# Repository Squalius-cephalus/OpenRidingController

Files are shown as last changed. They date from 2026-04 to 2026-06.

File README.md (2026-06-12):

# OpenRidingController
A horse riding game controller for the PC/Mac. The idea is to emulate basic horse riding behaviors and converts those to work a variety of video games.

The controller mainly uses **RP2040 Zero**, **TCRT5000** IR modules and 3D printed parts. Code uses **[CircuitPython 10](https://circuitpython.org/board/waveshare_rp2040_zero/)** for fast prototyping, later revisions may move to Arduino C or something similar.

Currently the controller can emulate keyboard, mouse and DirectInput controller, however, this wont work on any "keyboard to game console" adapter, because of how the USB composite system works.
## Revision 2
Latest revision uses a PCB, and the goal is to minimize the number of 3D printed parts. Strirrups uses an IMU sensors, so controller can be adapted to different frames easily.

OpenRidingController rev.2

Build guide and BOM in the works.

## Revision 1
Handwired design, frame, sensors etc uses many 3D printed parts. Not in active develoment. 

OpenRidingController rev.1

## Video
Video about the project (http://www.youtube.com/watch?v=zyoOwf0pp80 "OpenRidingController")

## Hardware Required

 - RP2040 Zero
 - 4 pcs TCRT5000 Infrared Reflective Sensor (with analog out)
 - [3D Printed parts, steel pipes and M3 hardware](https://github.com/Squalius-cephalus/OpenRidingController/tree/main/3D_files)

## Required Libraries

 - [Adafruit CircuitPython HID Library](https://github.com/adafruit/Adafruit_CircuitPython_HID/tree/main)
 - [Adafruit CircuitPython Nunchuk](https://github.com/adafruit/Adafruit_CircuitPython_Nunchuk)
 - Adafruit Neopixel
 - Bus Devices
 - Simple Math

## Circuit Diagram
circuit_diagram

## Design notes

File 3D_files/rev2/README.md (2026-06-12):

# 3D Printed Parts

It is recommended that the printed part be made from **PETG filament** rather than PLA filament. PLA is too brittle for frame parts.

## Parts for the module

**BOM**

 - 12x 	M3 Bolt 16mm
 - 4x   M3 Bolt 10mm
 - 12x  M3 Heatset insert OD 5mm
 - 2x 608zz Bearing
 
 **Printed parts**

- 1x	Case part 1 - `case_bottom.step`
- 1x	Case part 2 - `case_top.step` 
- 2x Reins case(Mirror the second one) - `reins_case.step`
- 2x Reins flap - `reins_flap.step`
- 2x Bearing collar - `reins_bearing_collar.step`

TODO: 
ADD IMAGES
ADD STIRRUP SENSOR

## Miscellaneous

### Reins Strap

**BOM**
 - 1 meter faux leather flat strap 15mm
 - ~1 meter 3mm paracord
 
 **Printed parts**

- 2x Strap adapter - `strap_adapter.step`

strap

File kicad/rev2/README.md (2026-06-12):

## Kicad Footprints

This project uses footprints from various repositories

 - [OLED Display 128x32](https://github.com/crides/kleeb/tree/master/display.pretty)
 - [Nunchuck Connector](https://gitlab.com/phodina/kicad-footprints/-/blob/nintendo/Connector.pretty/Nintendo_Wii_Peripheral_6Pin_Socket_Horizontal.kicad_mod)

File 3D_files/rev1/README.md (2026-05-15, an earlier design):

# 3D Printed Parts

The controller consists of FDM-printed parts, metal tubes, and M3 screws. It is recommended that the printed part be made from **PETG filament** rather than PLA filament. PLA is too brittle for frame parts.

## Parts for the frame

**BOM**

  - 3x	16mm stainless steel pipe 700mm
 - 32x 	M3 nut
 - 32x 	M3 Washer 7mm
 - 12x 	M3 Bolt 10mm
 - 24x 	M3 Bolt 16mm
 
 **Printed parts**

- 3x	Frame holder - `frame_main.step`
- 2x	Frame Connector - `frame_connector.step` 
- 4x Accessory Holder - `frame_accessory_holder.step`
- 2x Strap holder *optional* - `strap_holder.step`
frame

## Rein Sensor
You need to make two of these, only sunshade needs to be mirrored in the slicer software. The left and right parts are identical.

**BOM**
 - 2x 	M3 Washer 7mm
 - 7x 	M3 Bolt 10mm
 - 5x M3 Heatset insert OD 5mm
 - 1x 608zz Bearing
 - 2.5mm Elastic cord
 - Paracord, string etc
 - Sponge or some soft foam
 
 **Printed parts**

- 2x	Sunshade(mirror the second one) - `sunshade.step`
- 2x Sunshade small (optional) - `sunshade_small.step`
- 1x	Flap - `flap.step` 
- 1x Bearing holder - `bearing_holder.step`
- 1x Bearing collar - `bearing_collar.step`
- 1x Sensor holder - `sensor_holder.step`

You need 4x of M3 washers, bolts(10mm) and nuts for connecting one sensor to the accessory holder.

Rein Sensor

## Stirrup Sensor
You need to make two of these, the left and right parts are identical.

**BOM**
 - 1x M3 Bolt 10mm
 - 25mm strap
 - 25mm strap adjuster

 **Printed parts**

- 1x Stirrup - `stirrup.step`
- 1x Stirrup plate - `stirrup_antislip_holder.step`
- 1x Stirrup Reflector - `stirrup_reflector_plate.step`
- 1x Sunshade (If possible, print from TPU)  - `sunshade.step`
- 1x Sensor holder - `sensor_holder.step`

You need 4x of M3 washers, bolts(10mm) and nuts for connecting one sensor to the accessory holder.

Stirrup Sensor

## Nunchuk Connector

**BOM**
 - 2x M3 Bolt 16mm
 - 2x M3 Heatset insert OD 5mm
 - 3mm zip tie
 - 1x "I2C for Wii, WiiChuck Nunchuk Board"
 
 **Printed parts**

- 1x Lid - `nunchuk_connector_lid.step`
- 1x Case - `nunchuk_connector_body.step`
- 1x Holder - `nunchuk_connector_holder.step`
- 1x Controller holder - `nunchuk_controller_holder.step`
- 
You need 4x of M3 washers, bolts(10mm) and nuts for connecting the controller holder to the accessory holder.

nunchuk

## Electronic Box

Currently there is no PCB design so electronics need to be handwired. 

**BOM**
 - 4x M3 Bolt 10mm
 - 6x M3 Heatset insert OD 5mm
 - 70x50mm Perfboard
 - 2x short M3 bolt+washers
 - 6x MX compatible keyswitches/keycaps
 - Solder, wire etc
 
 **Printed parts**

- 1x Lid - `electronics_box_lid.step`
- 1x Case - `electronics_box_main_body.step`

You need 4x of M3 washers, bolts(10mm) and nuts for connecting the controller holder to the accessory holder.

electronics

## Miscellaneous

### Reins Strap

**BOM**
 - 1 meter faux leather flat strap 15mm
 - ~1 meter 3mm paracord
 
 **Printed parts**

- 2x Strap adapter - `strap_adapter.step`

strap

### Bolt Covers
 **Printed parts**

Works with most of the frame parts.

- Bolt Cover - `bolt_cover.step`

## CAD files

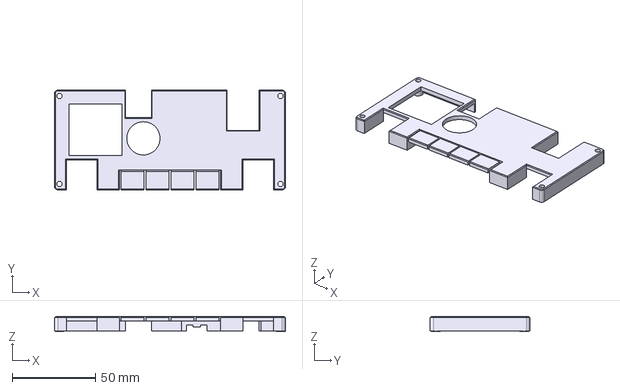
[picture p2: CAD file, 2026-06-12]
3D_files/rev2/case_top.step
139.0 x 60.0 x 8.80 mm

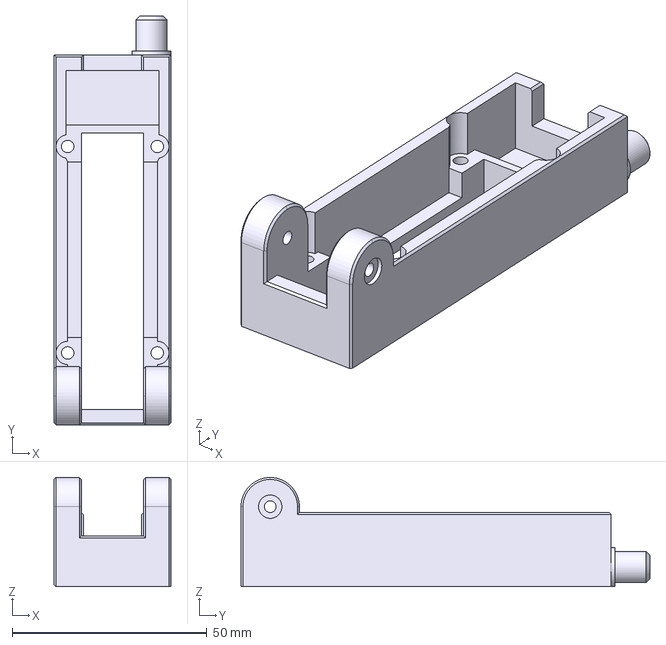
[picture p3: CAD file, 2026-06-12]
3D_files/rev2/reins_case.step
30.0 x 105.0 x 28.0 mm

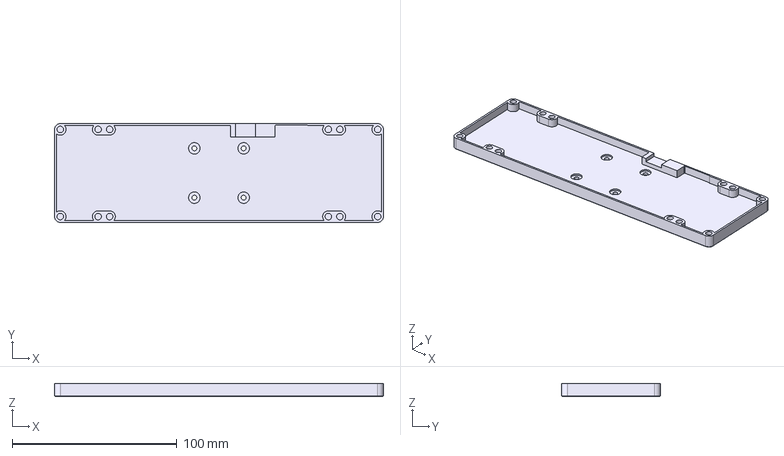
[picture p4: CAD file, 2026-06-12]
3D_files/rev2/case_bottom.step
200.0 x 60.0 x 8.00 mm

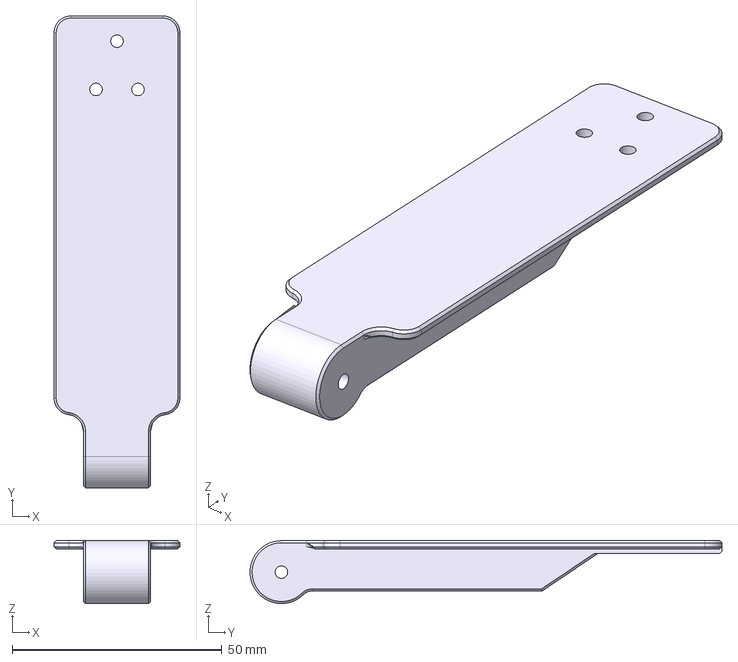
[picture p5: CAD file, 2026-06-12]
3D_files/rev2/reins_flap.step
30.0 x 112.5 x 15.1 mm

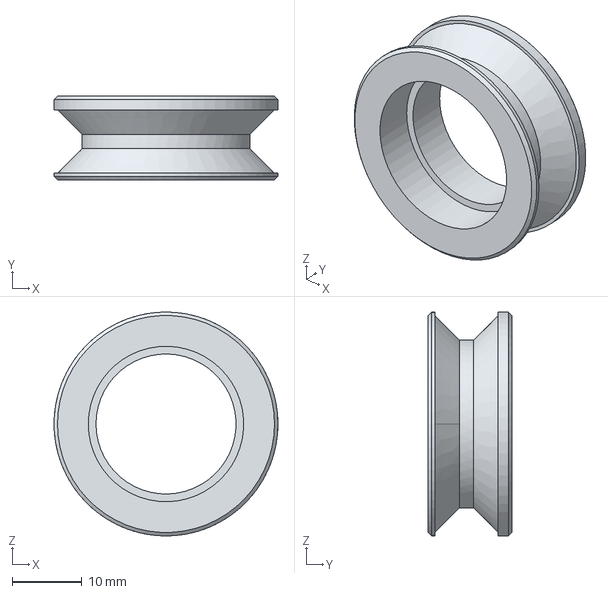
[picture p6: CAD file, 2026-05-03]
3D_files/rev2/reins_bearing_collar.step
32.0 x 12.0 x 32.0 mm

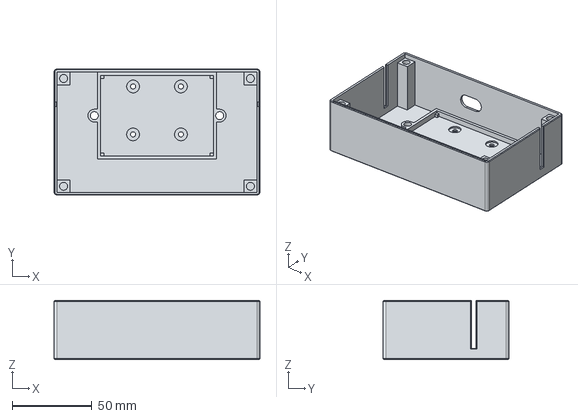
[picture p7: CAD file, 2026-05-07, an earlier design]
3D_files/rev1/STEP/electronics/electronics_box_main_body.step
129.0 x 79.0 x 37.0 mm

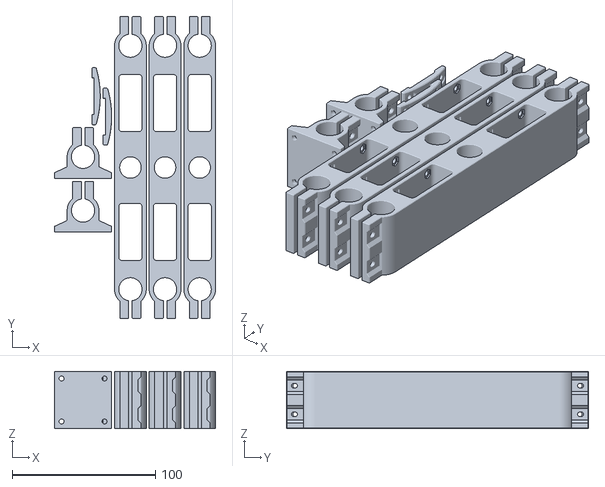
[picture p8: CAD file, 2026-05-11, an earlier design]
3D_files/rev1/STL/frame/main_frame.stl
112.6 x 211.0 x 40.0

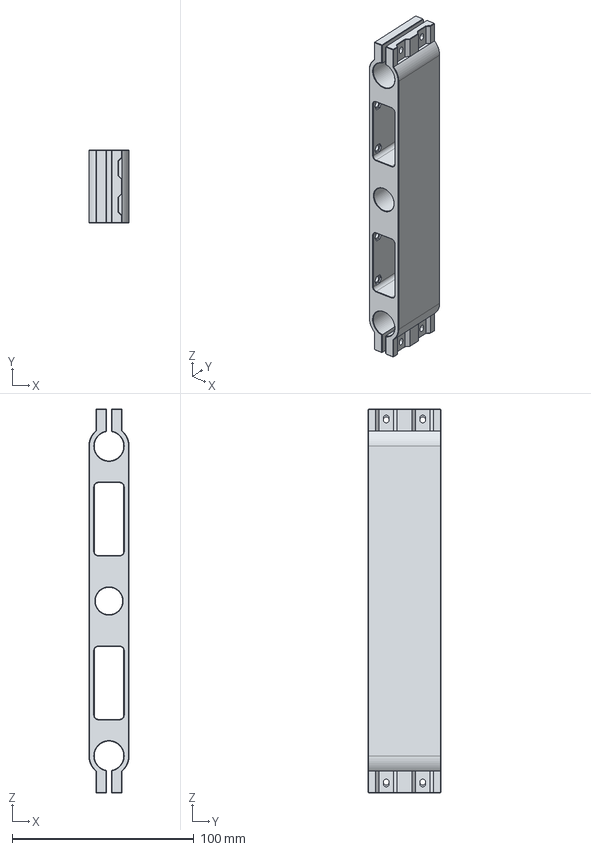
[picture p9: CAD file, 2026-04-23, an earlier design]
3D_files/rev1/STEP/frame/frame_main.step
22.2 x 40.0 x 211.0 mm

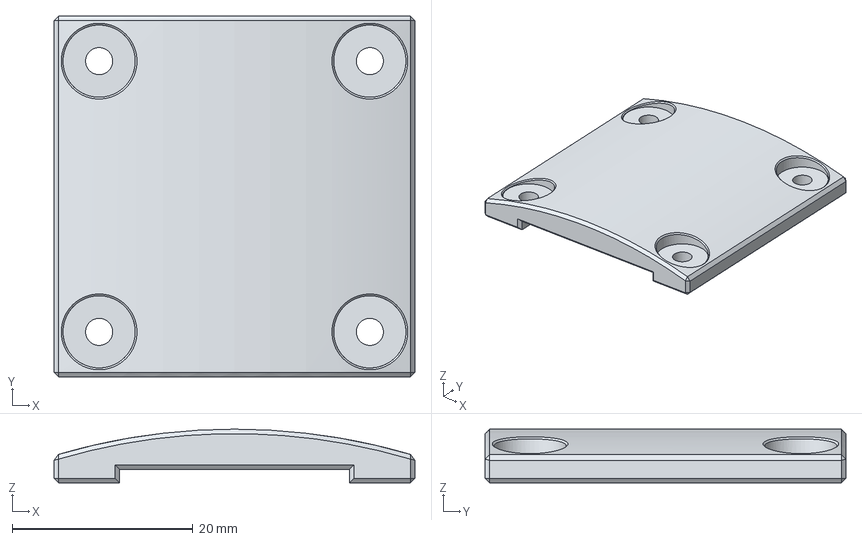
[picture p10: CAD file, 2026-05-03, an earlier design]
3D_files/rev1/STEP/frame/strap_holder.step
40.0 x 40.0 x 5.95 mm

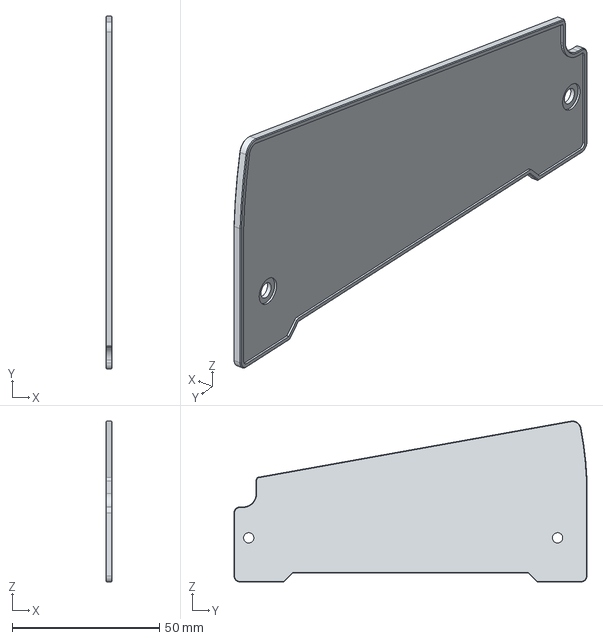
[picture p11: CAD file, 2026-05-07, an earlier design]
3D_files/rev1/STEP/reins/sunshade_small.step
2.00 x 120.0 x 54.7 mm

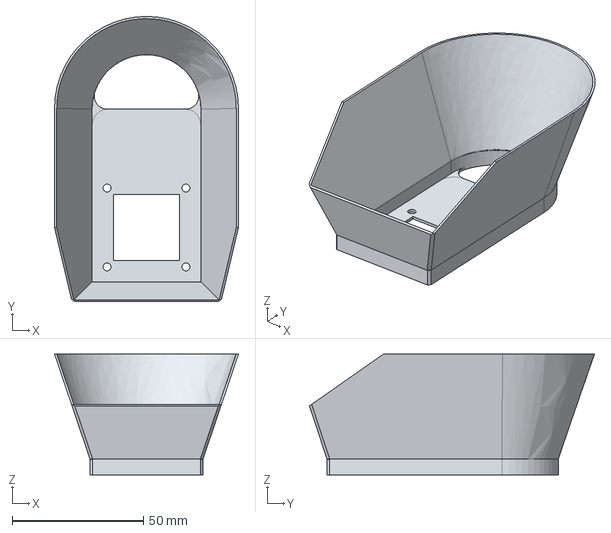
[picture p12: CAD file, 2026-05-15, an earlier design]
3D_files/rev1/STEP/stirrups/sunshade_smaller_thinner.step
70.0 x 108.5 x 46.0 mm

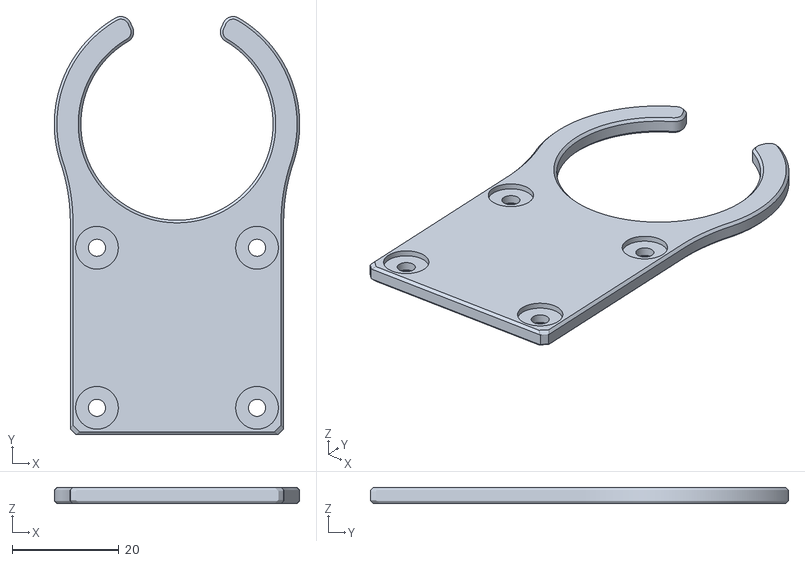
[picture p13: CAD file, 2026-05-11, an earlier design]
3D_files/rev1/STL/electronics/nunchuk_holder.stl
46.0 x 78.3 x 3.00

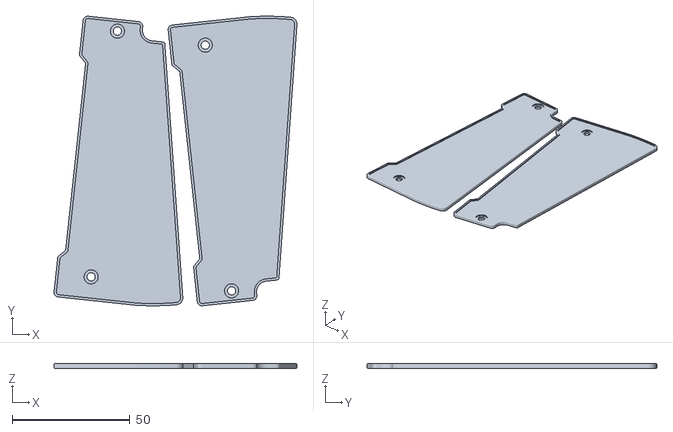
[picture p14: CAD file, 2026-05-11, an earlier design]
3D_files/rev1/STL/reins/sunshades_small.stl
103.2 x 123.1 x 2.00

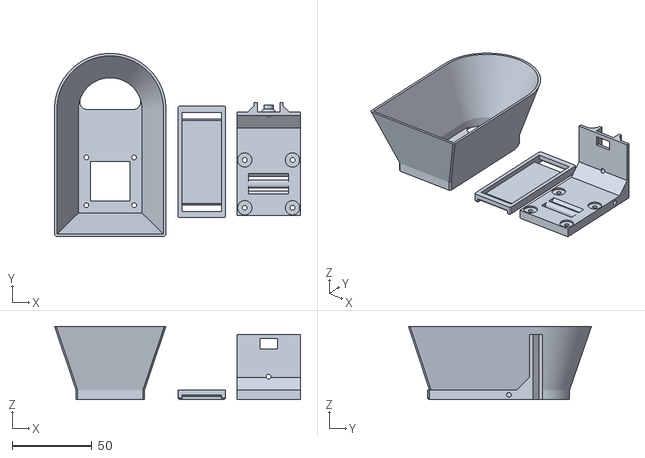
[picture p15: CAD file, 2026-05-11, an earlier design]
3D_files/rev1/STL/stirrups/sensor_holder_w_sunshade.stl
154.5 x 115.0 x 46.0

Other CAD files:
3D_files/rev1/STEP/electronics/electronics_box_lid.step
3D_files/rev1/STEP/frame/frame_connector.step
3D_files/rev1/STEP/misc/strap_adapter.step
3D_files/rev1/STEP/reins/bearing_holder.step
3D_files/rev1/STEP/electronics/nunchuk_connector_body.step
3D_files/rev1/STEP/electronics/nunchuk_connector_holder.step
3D_files/rev1/STEP/electronics/nunchuk_connector_lid.step
3D_files/rev1/STEP/electronics/nunchuk_controller_holder.step
3D_files/rev1/STEP/frame/frame_accessory_holder.step
3D_files/rev1/STEP/misc/bolt_cover.step
3D_files/rev1/STEP/reins/flap.step
3D_files/rev1/STEP/reins/sensor_holder.step
3D_files/rev1/STEP/reins/sunshade.step
3D_files/rev1/STEP/stirrups/Stirrup.step
3D_files/rev1/STEP/stirrups/antislip.stl
3D_files/rev1/STEP/stirrups/sensor_holder.step
3D_files/rev1/STEP/stirrups/stirrup_antislip_holder.step
3D_files/rev1/STEP/stirrups/stirrup_reflector_plate.step
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

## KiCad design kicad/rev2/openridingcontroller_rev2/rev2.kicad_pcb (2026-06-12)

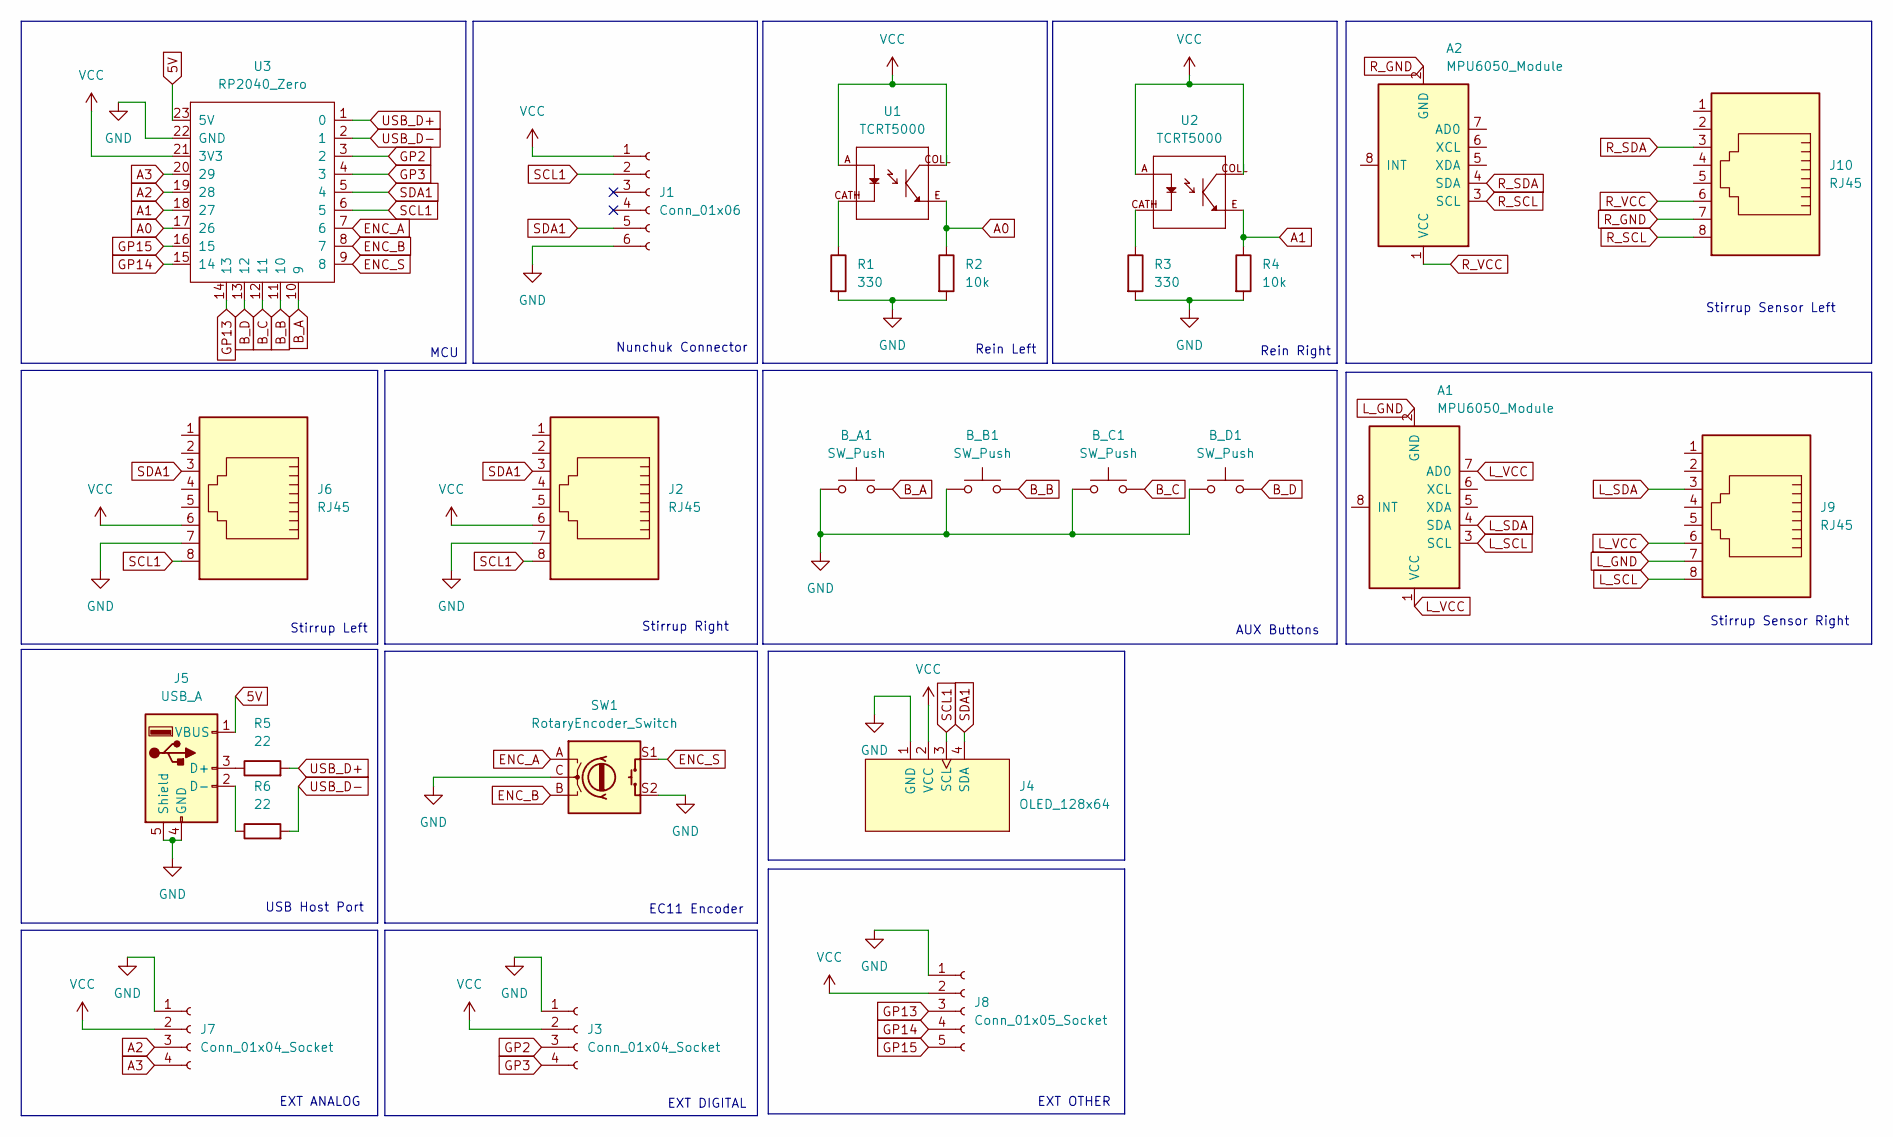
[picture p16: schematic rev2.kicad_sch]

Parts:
A1, A2: MPU6050_Module
B_A1: SW_Push; SW_PUSH_6mm_H5mm
B_B1: SW_Push; SW_PUSH_6mm_H5mm
B_C1: SW_Push; SW_PUSH_6mm_H5mm
B_D1: SW_Push; SW_PUSH_6mm_H5mm
J1: Conn_01x06; Nintendo_Wii_Peripheral_5Pin_Card_edge
J2, J6, J9, J10: RJ45; RJ45_OST_PJ012-8P8CX_Vertical
J3, J7: Conn_01x04_Socket; PinHeader_1x04_P2.54mm_Vertical
J4: OLED_128x64
J5: USB_A; USB_A_Molex_67643_Horizontal
J8: Conn_01x05_Socket; PinHeader_1x05_P2.54mm_Vertical
R1, R3: 330; R_Axial_DIN0204_L3.6mm_D1.6mm_P7.62mm_Horizontal
R2, R4: 10k; R_Axial_DIN0204_L3.6mm_D1.6mm_P7.62mm_Horizontal
R5, R6: 22; R_Axial_DIN0204_L3.6mm_D1.6mm_P7.62mm_Horizontal
SW1: RotaryEncoder_Switch; RotaryEncoder_Alps_EC11E-Switch_Vertical_H20mm
U1, U2: TCRT5000; OPTO_TCRT5000; PARTREV 1.7
U3: RP2040_Zero

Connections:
5V: J5.1 (VBUS), U3.23 (5V)
A0: R2.1, U1.E, U3.17 (26)
A1: R4.1, U2.E, U3.18 (27)
A2: J7.3, U3.19 (28)
A3: J7.4, U3.20 (29)
B_A: B_A1.2, U3.10 (9)
B_B: B_B1.2, U3.11 (10)
B_C: B_C1.2, U3.12 (11)
B_D: B_D1.2, U3.13 (12)
ENC_A: SW1.A, U3.7 (6)
ENC_B: SW1.B, U3.8 (7)
ENC_S: SW1.S1, U3.9 (8)
GND: B_A1.1, B_B1.1, B_C1.1, B_D1.1, J1.6, J2.7, J3.1, J4.1 (GND), J5.4 (GND), J5.5 (Shield), J6.7, J7.1, J8.1, R1.2, R2.2, R3.2, R4.2, SW1.C, SW1.S2, U3.22 (GND)
GP2: J3.3, U3.3 (2)
GP3: J3.4, U3.4 (3)
GP13: J8.3, U3.14 (13)
GP14: J8.4, U3.15 (14)
GP15: J8.5, U3.16 (15)
L_GND: A1.2 (GND), J9.7
L_SCL: A1.3 (SCL), J9.8
L_SDA: A1.4 (SDA), J9.3
L_VCC: A1.1 (VCC), A1.7 (AD0), J9.6
unnamed: J5.3 (D+), R5.1
unnamed: J5.2 (D-), R6.1
unnamed: R1.1, U1.CATH
unnamed: R3.1, U2.CATH
R_GND: A2.2 (GND), J10.7
R_SCL: A2.3 (SCL), J10.8
R_SDA: A2.4 (SDA), J10.3
R_VCC: A2.1 (VCC), J10.6
SCL1: J1.2, J2.8, J4.3 (SCL), J6.8, U3.6 (5)
SDA1: J1.5, J2.3, J4.4 (SDA), J6.3, U3.5 (4)
USB_D+: R5.2, U3.1 (0)
USB_D-: R6.2, U3.2 (1)
VCC: J1.1, J2.6, J3.2, J4.2 (VCC), J6.6, J7.2, J8.2, U1.A, U1.COLL, U2.A, U2.COLL, U3.21 (3V3)

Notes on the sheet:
EXT DIGITAL
USB Host Port
Stirrup Left
AUX Buttons
Rein Right
Stirrup Sensor Right
EC11 Encoder
MCU
EXT OTHER
EXT ANALOG
Stirrup Right
Rein Left
Nunchuk Connector
Stirrup Sensor Left

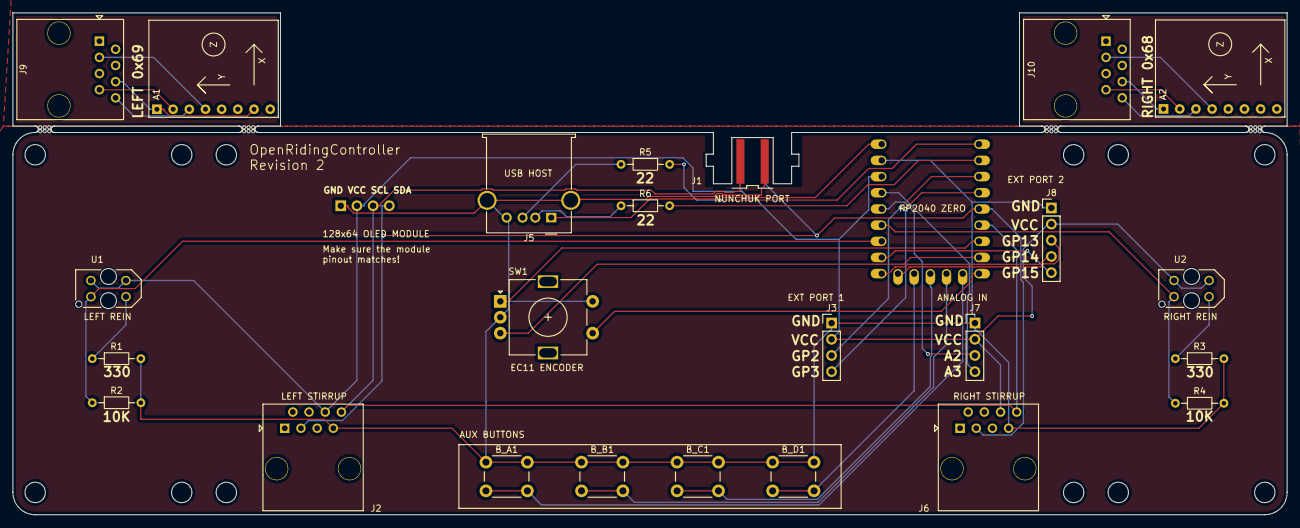
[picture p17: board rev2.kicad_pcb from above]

Board: 2 copper layers, 200.0 x 78.8 mm, 30 parts (0 on the bottom side), 35 nets.

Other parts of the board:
mouse-bite-1mm-3mm, mouse-bite-1mm-3mm#2, mouse-bite-1mm-3mm#3, mouse-bite-1mm-3mm#4: VAL**; mouse-bite-1mm-3mm

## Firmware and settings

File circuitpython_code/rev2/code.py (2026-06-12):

"""
OpenRidingController Revision 2

This module initializes all hardware input devices, manages controller
profiles, processes horse control logic, and updates output devices
during the main loop.

License: MIT License
Copyright (c) 2026 Squalius-cephalus

"""
import json
import board
import digitalio
import neopixel
import time
from inputs.buttons import ButtonHandler
from horse_logic import HorseLogicHandler
from inputs.reins import ReinsHandler
from inputs.stirrups import StirrupsHandler
from inputs.nunchuk import NunchukHandler
from outputs.output_manager import OutputManager
from utils.debug import log
from outputs.oled import OLEDHandler
import busio
i2c = busio.I2C(
            board.GP5,  # SCL
            board.GP4,  # SDA
            frequency=100000
        )
# Initialize the onboard NeoPixel LED.
led = neopixel.NeoPixel(board.GP16, 1, brightness=0.3, auto_write=True)

# Load controller profiles from the RP2040 Zero.
with open("/profiles.json", "r") as f:
    data = json.load(f)

setup_done = False

loaded_profiles = data["profiles"]

# Configure profile selection button.
profile_button = digitalio.DigitalInOut(board.GP15)
profile_button.direction = digitalio.Direction.INPUT
profile_button.pull = digitalio.Pull.UP

# Configure pause button.
pause_button = digitalio.DigitalInOut(board.GP14)
pause_button.direction = digitalio.Direction.INPUT
pause_button.pull = digitalio.Pull.UP

# Configure encoder button.
encoder_button = digitalio.DigitalInOut(board.GP8)
encoder_button.direction = digitalio.Direction.INPUT
encoder_button.pull = digitalio.Pull.UP

class Controller:
    """
    Central coordinator for all controller input and output systems.

    This class is responsible for:
    - Updating hardware input handlers.
    - Sends rein and stirrup states to the horse control logic.
    - Gets processed states from horse logic.
    - Sending processed states to the output manager.
    """
    def __init__(self):
        """Initialize all hardware inputs and input handlers."""
        self.output_manager = OutputManager()
        self.reins_handler = ReinsHandler()
        self.stirrups_handler = StirrupsHandler(i2c)
        self.nunchuk_handler = NunchukHandler(i2c)
        self.horse_logic_handler = HorseLogicHandler()
        self.button_handler = ButtonHandler()
        self.nunchuk_connected = self.nunchuk_handler.is_connected()

    def update_inputs(self, current_time):
        """
        Update all input devices.

        Args:
            current_time: Current monotonic timestamp used for timed updates.
        """
        self.reins_handler.update()
        self.stirrups_handler.update()
        self.button_handler.update()
        if self.nunchuk_connected:
            self.nunchuk_handler.update(current_time)

    def get_states_from_inputs(self):
        """
        Merge all input states into a single dictionary.

        Returns:
            Combined input states from stirrups and reins handlers.
        """
        stirrup_states = self.stirrups_handler.get_states()
        reins_states = self.reins_handler.get_states()
        return stirrup_states | reins_states

    def set_new_profile(self, new_profile):
        """
        Apply a newly selected profile across all handlers.

        Args:
            new_profile: Profile configuration dictionary.
        """
        self.output_manager.set_new_profile(new_profile)
        self.nunchuk_handler.set_new_profile(new_profile)
        self.reins_handler.set_new_profile(profile_manager.current_profile["settings"])
        self.stirrups_handler.set_new_profile(
            profile_manager.current_profile["settings"]
        )

        self.output_manager.release_all()

    def release_all(self):
        """
        Release all inputs like toggle, hold etc.
        """
        self.output_manager.release_all()

    def update(self, current_time):
        """
        Execute a controller update cycle.

        This method:
        - Updates inputs.
        - Processes horse control logic.
        - Combines all controller states.
        - Pushes proceccess states to the output manager.

        Args:
            current_time: Current monotonic timestamp.
        """
        self.update_inputs(current_time)


        # Horse logic will process reins and stirrup states.
        self.horse_logic_handler.update_analog(self.reins_handler.get_analog_states())
        self.horse_logic_handler.update(self.get_states_from_inputs())

        # Merge states from all handlers.
        states = (
            self.horse_logic_handler.get_states()
            | self.button_handler.get_states()
            | self.nunchuk_handler.get_states()
        )
        self.output_manager.update(
            states,
            self.horse_logic_handler.get_analog_states(),
            self.nunchuk_handler.get_analog_states(),
            current_time,
        )


class OnboardLED:
    """
    Initialize the onboard LED controller.

    Args:
        neopixel_led: NeoPixel LED, onboard LED.
    """

    def __init__(self, neopixel_led):
        self.led = neopixel_led
        self.current_color = [255, 255, 255]

    def change_color(self, color):
        """
        Set the LED to a new color.

        Args:
            color: RGB color list.
        """
        self.led[0] = color
        self.current_color = color

    def get_color(self):
        """
        Returns:
            Current RGB color as list.
        """
        return self.current_color


class ProfileManager:
    """
    Handles profile selection.

    Profiles control configuration settings such as LED color,
    input sensitivity, and button mappings.
    """
    def __init__(self, profiles, passed_led):
        """
        Initialize the profile manager.

        Args:
            profiles: JSON list of profiles.
            passed_led: Onboard LED object used for visual feedback.
        """
        self.profiles = profiles
        self.led = passed_led
        self.current_index = -1
        self.current_profile = self.profiles[self.current_index]

    def get_profile_names(self):
        names = []
        for i in self.profiles:
            names.append(i["name"])
        return names

    def change_profile(self, index):
        """
        Cycle to the next available profile.

        Updates the LED color.

        Returns:
            The newly selected profile.
        """
        self.current_profile = self.profiles[index]
        self.current_index = index
        log("Active profile:", self.current_profile["name"])
        self.led.change_color(self.current_profile["settings"]["led_color"])
        time.sleep(0.3)
        return self.current_profile


onboard_led = OnboardLED(led)
profile_manager = ProfileManager(loaded_profiles, onboard_led)
controller = Controller()

settings = {
    "Mouse Sens.": {"value": 1, "min": 0.1, "max": 1, "step": 0.1},
    "Joystick Sens.": {"value": 1, "min": 0.1, "max": 1, "step": 0.1},
    "Stirrup Sens.": {"value": 1, "min": 0.1, "max": 1, "step": 0.1},
}

oled = OLEDHandler(i2c, profile_manager.get_profile_names(), settings)

def open_menu():
    time.sleep(0.5)
    controller.release_all()
    current_index = profile_manager.current_index
    profile = profile_manager.change_profile(oled.update(encoder_button, current_index))
    controller.set_new_profile(profile)
    oled.status(profile_manager.current_profile["name"])
    # settings does nothing
    #print(oled.get_settings())

# Main loop.
while True:
    current_time = time.monotonic()
    if not profile_button.value or not setup_done:
        new_profile = profile_manager.change_profile(0)
        controller.set_new_profile(new_profile)
        oled.status(new_profile["name"])
        setup_done = True

    if not encoder_button.value:
        open_menu()

    controller.update(current_time)

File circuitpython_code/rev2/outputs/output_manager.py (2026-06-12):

"""
This module takes all the states from the Horse Logic and
uses that to send keycodes and analog values to various
HID devices. This also process the profile mapping. 
"""

from outputs.keyboard import KeyboardOutput
from outputs.mouse import MouseOutput
from outputs.gamepad import GamepadOutput
from adafruit_simplemath import map_range
import time
from utils.debug import log

keyboard = KeyboardOutput()
mouse = MouseOutput()
gamepad = GamepadOutput()

DEVICES = {
    "keyboard": keyboard,
    "gamepad": gamepad,
    "analog": gamepad,
    "mouse_move": mouse,
    "mouse_button": mouse,
}
ANALOG_MODES = {"mouse_move", "analog"}

class OutputManager:
    def __init__(self):
        self.buttons = {}
        self.previous_states = {}
        self.hold_keys = {}
        self.toggle_keys = {}
        self.reserved_keys = []
        self.macro_keys = []
        self.macro_timer = 0
        self.rein_mode = {}

        self.tap_time = 0.1

        self.possible_actions = {
            "hold": self.add_hold_keys,
            "tap": self.add_hold_keys,
            "toggle": self.handle_toggle_keys,
            "toggle_on": self.handle_toggle_keys,
            "toggle_off": self.handle_toggle_keys,
            "multitap": self.handle_multitap_keys,
        }

    def update(
        self, states, reins_analog_amount, nunchuk_analog=None, current_time=None
    ):
        """
        Update what keys/buttons need to be pressed or released.
        """
        if current_time is None:
            current_time = time.monotonic()

        # Multitap appeds to this dictionary, this fakes button presses.
        if self.reserved_keys:
            if not self.hold_keys:
                a = len(self.reserved_keys) - 1
                self.parse_input(self.reserved_keys[a], current_time)
                self.reserved_keys.pop(0)

        for i, activated in states.items():
            if activated:
                try:
                    button = self.buttons[i]
                except KeyError as e:
                    log("Profile is broken! Missing: ", e)
                    button = {"mode": None}

                mode = button.get("mode", "gamepad")
                if mode == "macro":
                    log("Macro detected")
                    for ii in button.get("macro"):
                        self.macro_keys.append(ii)
                elif mode is None:
                    log("Button skipped")
                else:
                    self.parse_input(button, current_time)

        self.release_hold_keys(current_time)
        self.update_reins_output(current_time, reins_analog_amount)
        if nunchuk_analog is not None:
            self.handle_nunchuk_analog(nunchuk_analog)

        if self.macro_keys:
            if current_time >= self.macro_timer:
                if self.macro_keys[0]["mode"] == "wait":
                    self.macro_timer = self.macro_keys[0]["value"] + current_time
                else:
                    self.parse_input(self.macro_keys[0], current_time)
                self.macro_keys.pop(0)

    def parse_input(self, button, current_time):
        """
        Gets data what button is pressed and parses what action it needs to do.
        """
        mode = self.get_valid(button, "mode", "keyboard", DEVICES.keys())
        key = self.get_with_default(button, "keycode", "A")
        action = self.get_valid(
            button,
            "action",
            "tap",
            {"tap", "hold", "toggle", "toggle_on", "toggle_off", "multitap"},
        )
        value = self.get_with_default(button, "value", 1)
        analog_value = self.get_with_default(button, "analog_value", 127)

        act = self.possible_actions[action]

        act(key, value, mode, action, current_time, analog_value)

    def add_hold_keys(self, key, value, mode, action, current_time, analog_value):
        """
        Adds keycode and current time to hold keys dict,
        after that presses the key.
        """
        if action == "tap":
            value = self.tap_time
        expiry = current_time + value
        self.hold_keys[key] = [mode, expiry]
        self.press_key(mode, key, analog_value)

    def handle_multitap_keys(self, key, value, mode, _, __, analog_value):
        """
        Fills a list to fake Tap actions.
        """
        log("Multitap detected")
        for i in range(int(value)):
            fake_button = {
                "mode": mode,
                "keycode": key,
                "action": "tap",
                "value": 0,
                "analog_value": analog_value,
            }
            self.reserved_keys.append(fake_button)

    def handle_toggle_keys(self, key, _, mode, action, __, analog_value):
        """
        Handles toggle action.
        """
        if self.toggle_keys.get(key) == mode:
            if action == "toggle" or action == "toggle_off":
                del self.toggle_keys[key]
                self.release_key(mode, key)
        else:
            if action != "toggle_off":
                self.toggle_keys[key] = mode
                self.press_key(mode, key, analog_value)

    def release_hold_keys(self, current_time):
        """
        Releases keys that are held down, if enough time has passed.
        """
        to_remove = []
        for key, (mode, expiry) in self.hold_keys.items():
            if current_time >= expiry:
                to_remove.append([mode, key])

        for key in to_remove:
            self.release_key(key[0], key[1])
            self.hold_keys.pop(key[1])

    def press_key(self, mode, key, analog_value=None):
        """
        Send keycode to press, or if device is analog it sends analog value to move cursor/joystick.
        """
        device = DEVICES.get(mode)

        if analog_value is not None and mode in ANALOG_MODES:
            device.move(key, analog_value, 1)
            log(mode, key, "moved to", analog_value)
        else:
            device.press(key)
            log(mode, key, "pressed")

    def release_key(self, mode, key):
        """
        Send keycode to release, or if device is analog it resets cursor/joystick to 0.
        """
        device = DEVICES.get(mode)
        if mode in ANALOG_MODES:
            device.move(key, 0, 1)
            log(mode, key, "moved to", 0)

        else:
            device.release(key)
            log(mode, key, "released")

    def release_all(self):
        """
        Resets toggles, held keys and forces devices to release all the keys/axis.
        """
        mouse.release_all()
        keyboard.release_all()
        gamepad.release_all()
        self.hold_keys = {}
        self.toggle_keys = {}
        self.reserved_keys = []
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

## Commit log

2026-04-23 Moved code to own directory, added missing STEP files for the frame
    [M3_accessory_holder.step, Stirrup.step, frame_component_small.step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]
2026-04-24 Added basic error handling for nunchuck and flick detection for it
    [output.py]
2026-04-25 Moved nunchuck code to own class/file, simpler error handling when nunchuck controller is disconnected
    [code.py, mouse_output.py, output.py]
2026-04-26 Controller sends UART data over GP12, can be converted to different game outputs
2026-04-27 Removed unused code, profile reworked and output manager redone
    [code.py, gamepad_output.py, mouse_output.py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]
2026-04-27 UART works when controller is not connected to PC
2026-05-01 Stirrups logic is now much better, needs better calibration. Stirrups and reins input values are now interpolated
2026-05-03 Added 3D models for the frame and most of the sensors
    [bearing_collar.step, bearing_holder.step, flap.step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]
2026-05-06 Debug function for later, code optimization, added missing settings and fixed typos
    [code.py, digital_input.py, gamepad_output.py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]
2026-05-07 More CAD files, small bug fixes
    [bearing_holder.step, bolt_cover.step, electronics_box_lid.step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]
2026-05-10 UART communication disabled for now
2026-05-11 Added STL files
    [accessory_holders.stl, antislip.stl, electronic_box.stl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]
2026-05-15 Repository cleanup, fixing "nunchuck" to "nunchuk" and removed UART logic
    [nunchuk_connector.stl, nunchuk_connector_body.step, nunchuk_connector_holder.step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]
2026-05-16 Little bit of clone cleanup and added most of missing docstrings
    [code.py, digital_input.py, gamepad_output.py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]
2026-05-23 Fixed that the I2C wont block the USB out, also some small bug fixes
    [mouse_output.py, nunchuk.py, reins_input.py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]
2026-06-12 Moving files and adding missing files for the revision 2.
    [case_bottom.step, case_top.step, reins_bearing_collar.step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]
